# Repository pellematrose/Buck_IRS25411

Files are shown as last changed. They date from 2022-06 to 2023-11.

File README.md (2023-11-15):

# Buck_IRS25411
High Voltage Buck featuring IRS25411 LED driver.
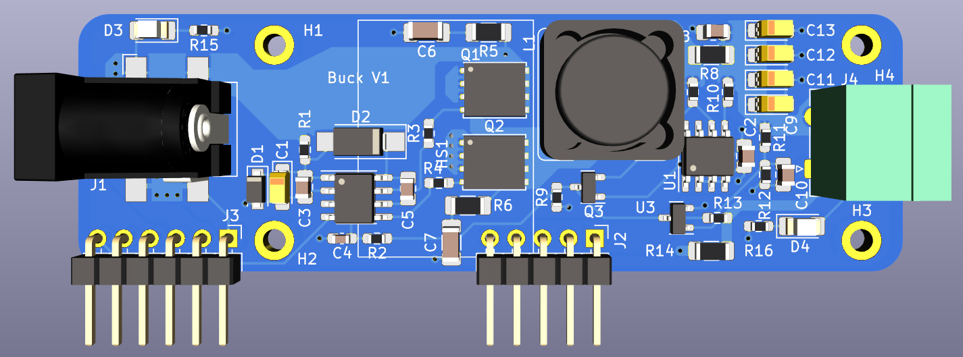
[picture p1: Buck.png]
Buck

The pinheaders offers the opportunity to use it as module on a other PCB.

The IRS25411 is a hysteretic Buck driver for LED applications.
Hysteretic means that there is no fixed frequency but it switches with over and undershooting the threshold level of the feedback pin with the current ripple.
Due to the feedback voltage of 0.5V it is not worth driving more than 1A of current. The needed current sensing resistor results to R = 0.5V / 1A = 0.5Ohms. The power losses are Pls = 0.5V * 1A = 0.5W. This is already to much for a standard 1206 resistor. Using multiple resistors in parallel it might work.

In this design the current sensing resistor moved directly behind the inductor and a op-amp is driving a pnp transistor to provide an appropriate voltage to the feedback pin. Thus, a constant current is maintained.
Additionally, an other part of the circuitry around the TS431 is regulating the voltage.

In parallel operation both CC and CV regulators are active. When the maximum current is flowing the voltage drops and the buck is working in CC mode.
When the maximum current is not flowing the voltage is clipped at the voltage set and the buck is working in CV mode.

The schematic offers the opportunity to assemble the pcb in three ways:
1. Infineon typical application with low side shunt (tested and works)
2. High current CC mode with the op-amp
3. CV mode with TS431 (tested and works)
4. Combined high current CC and CV mode

The design contains a routing mistake:
The connection between VS and Inductor is missing.

Schematics:
1. Infineon typical application with low side shunt
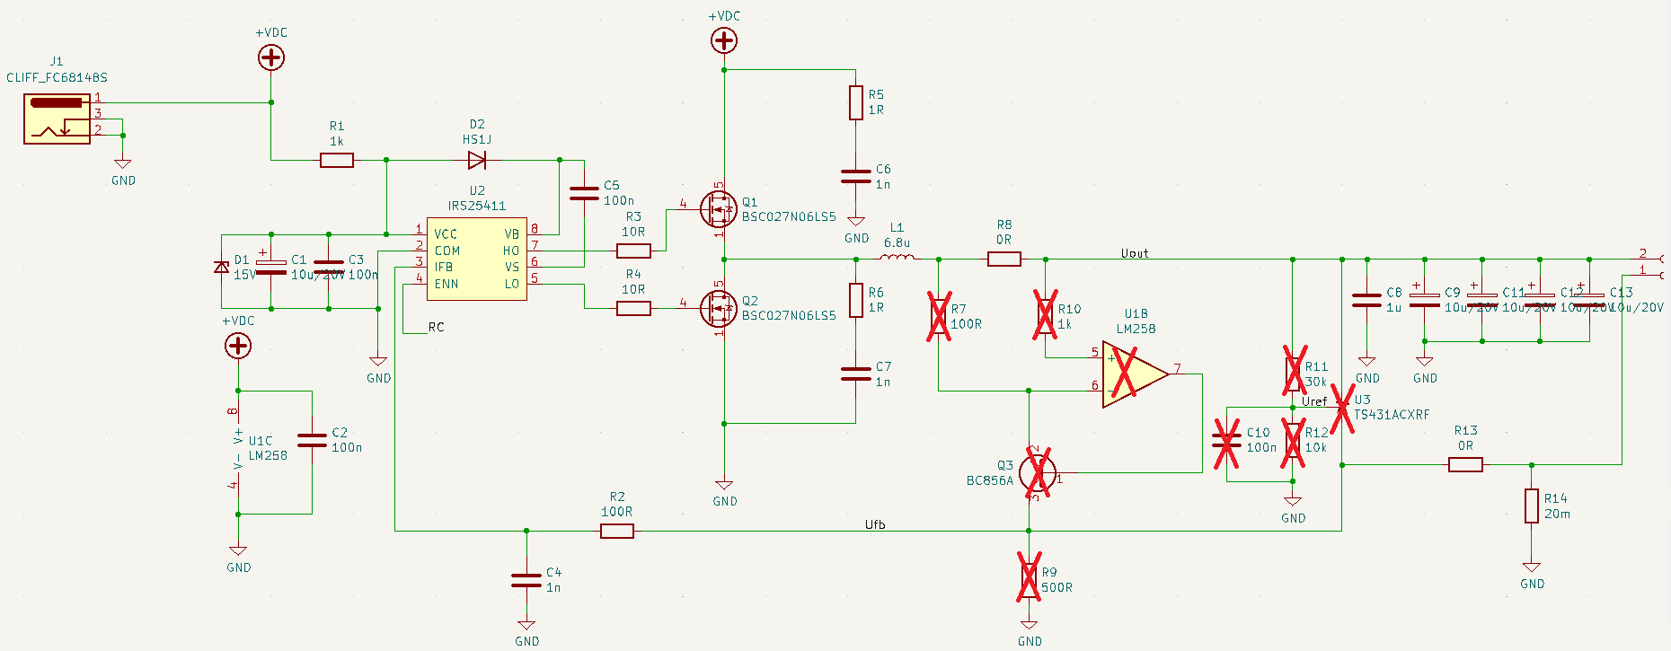
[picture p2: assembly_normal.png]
Buck_Schematic_default


2. High current CC mode with the op-amp
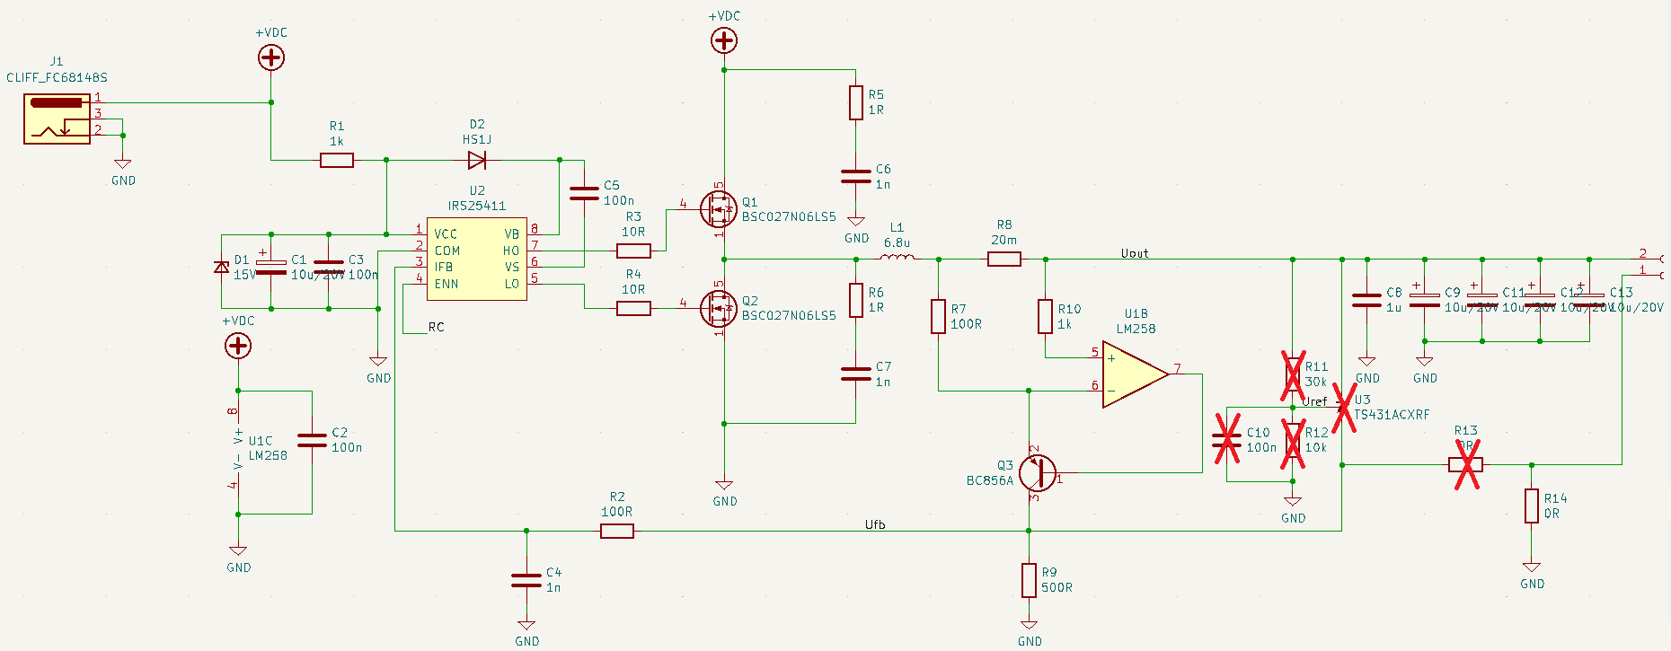
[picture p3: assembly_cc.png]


3. CV mode with TS431
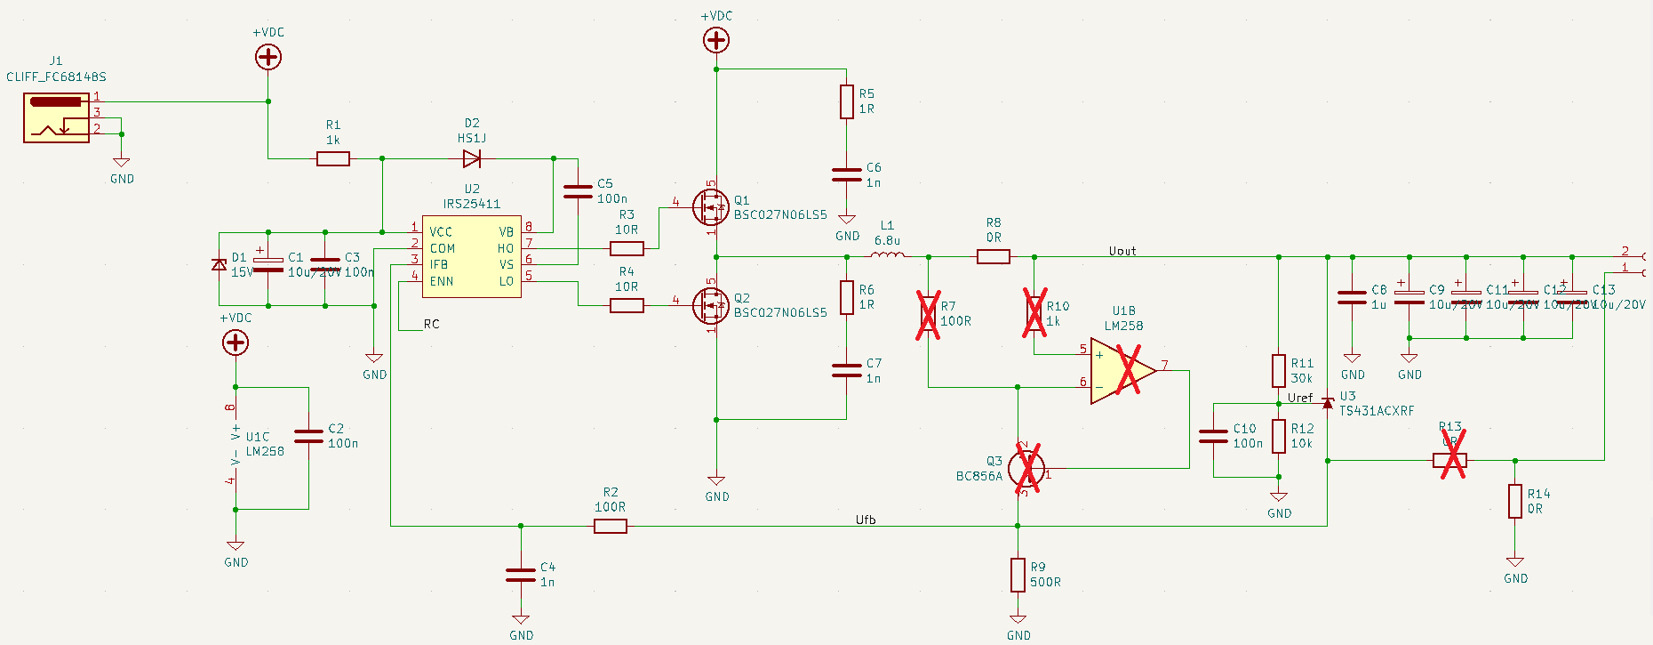
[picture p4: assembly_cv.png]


4. Combined high current CC and CV mode
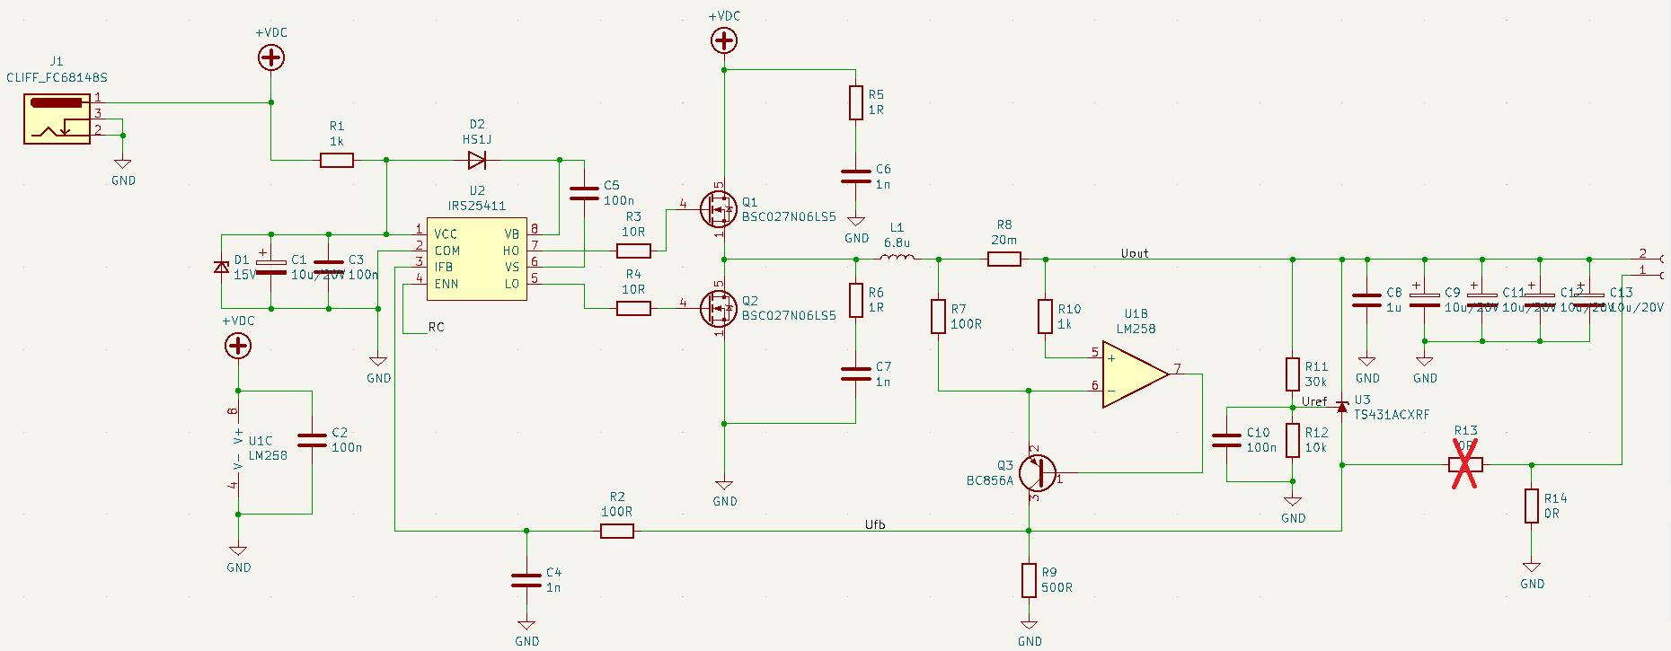
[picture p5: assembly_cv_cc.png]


To make it easy to adjust some component values the excel file may help you understand how the values are calculated.

I got the main inspiration from various application notes about the buck converter.  
[TI CC CV converter](https://www.ti.com/lit/an/snva829/snva829.pdf)  
[Electronics Stackexchange](https://electronics.stackexchange.com/questions/458384/cc-cv-buck-controller)  
[Buck converter design](https://www.mouser.de/pdfdocs/BuckConverterDesignNote.pdf)

Furthermore, here some links to usefull sites about mosfet losses:  
[Infineon MOSFET Losses Appnote](https://community.infineon.com/gfawx74859/attachments/gfawx74859/MOSFET/285/4/MOSFET%20Power%20Losses%20Calculation%20Using%20the%20Data-Sheet%20Parameters.pdf)  
[Youtube with Dr. K](https://www.youtube.com/watch?v=RViwOc4g-gw)</p>

The Buck design is only tested to 30V input voltage.
If you want to make a real high voltage buck you need to recalculate some components:
- R1 to limit the input current to the driver IC
- Q1, Q2 MOSFET Vds rating
- L1 Inductor
- Supply for the OpAmp (only ratet up to 30V)

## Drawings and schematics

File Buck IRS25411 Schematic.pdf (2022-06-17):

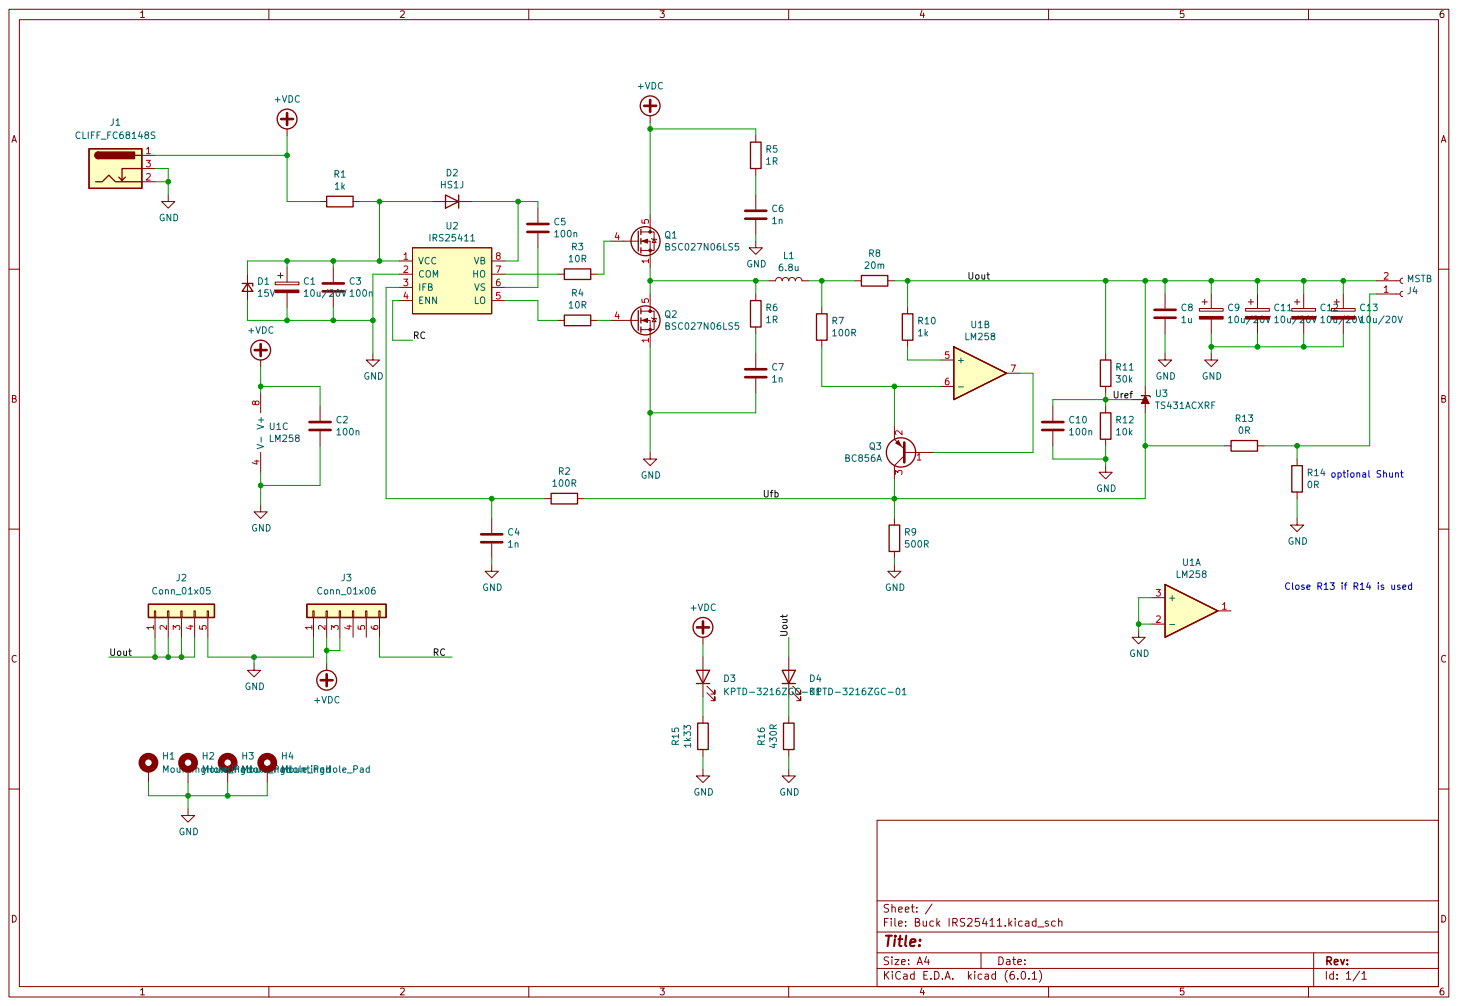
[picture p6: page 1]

VCC 1 COM 2

IFB 3 ENN 4

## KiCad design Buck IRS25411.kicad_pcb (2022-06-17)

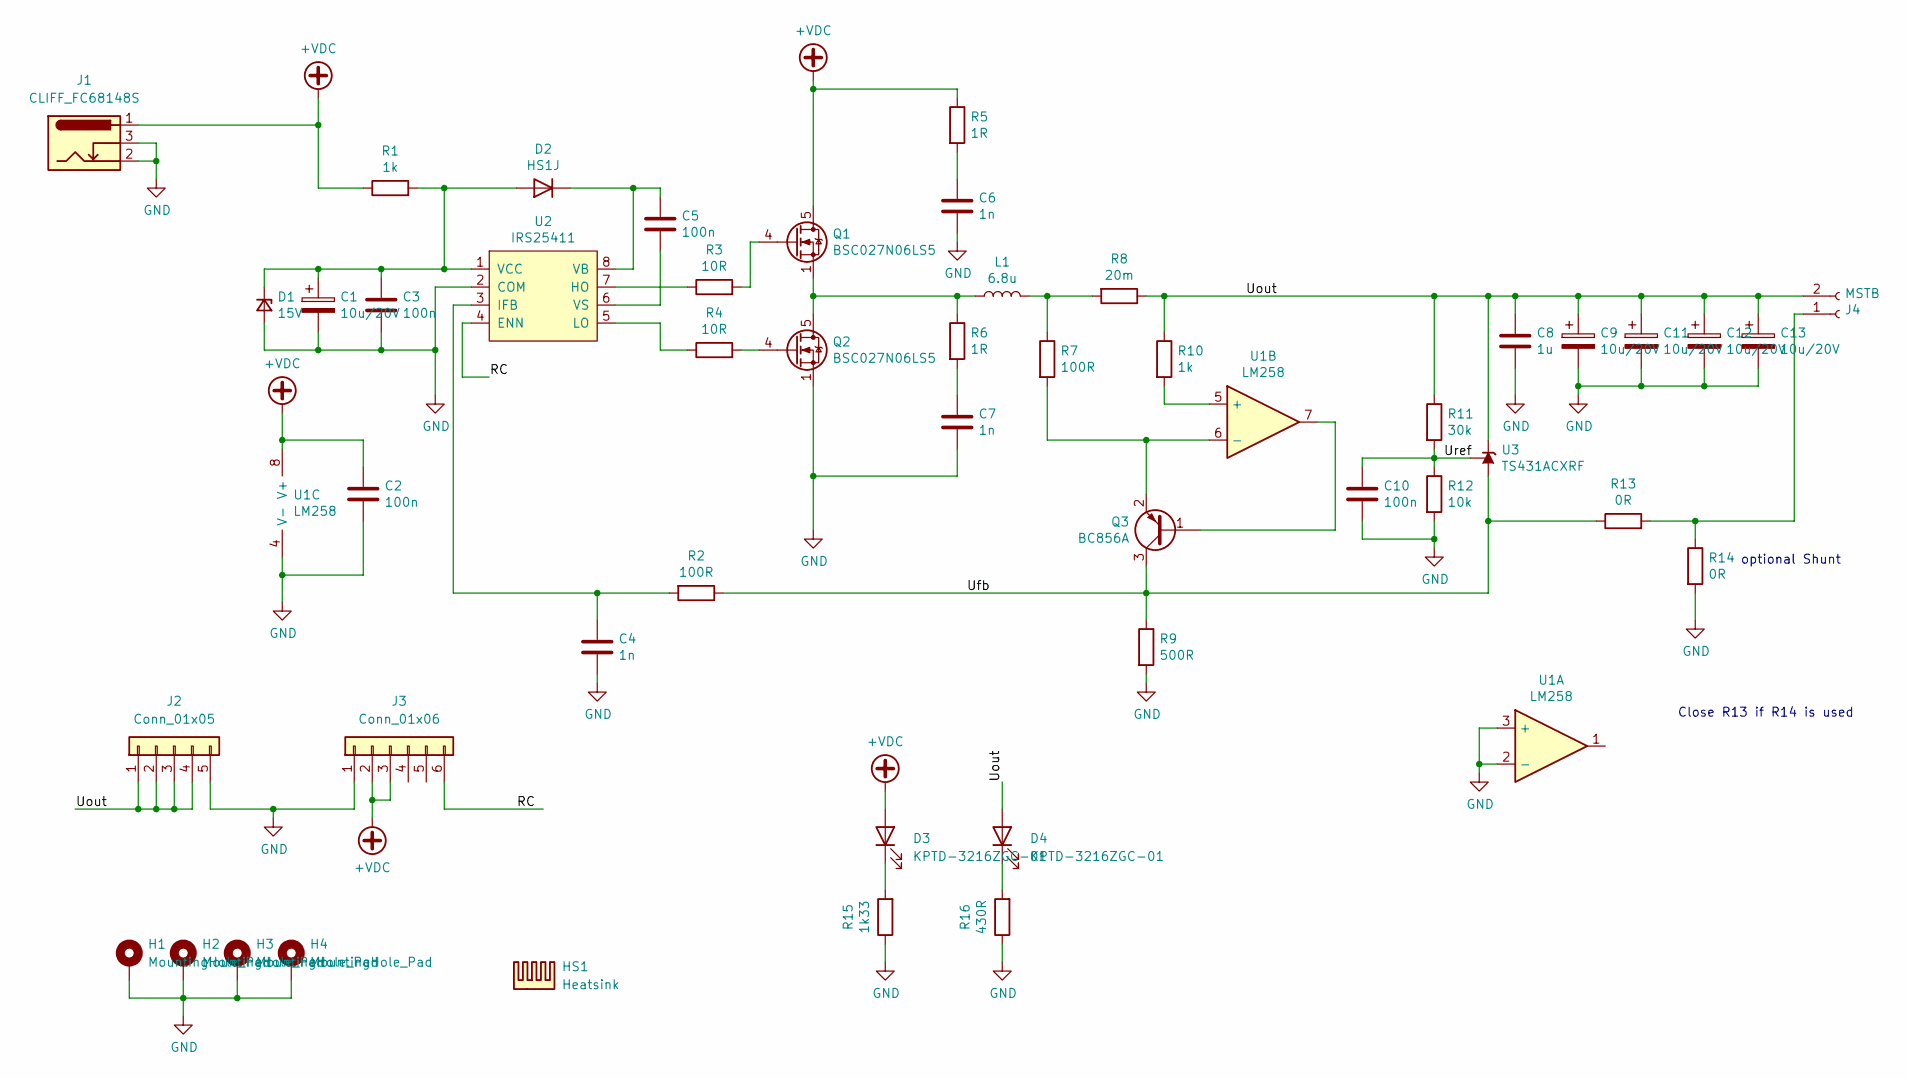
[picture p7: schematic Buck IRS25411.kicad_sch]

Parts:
C1, C9, C11, C12, C13: 10u/20V; CP_EIA-3216-18_Kemet-A_Pad1.58x1.35mm_HandSolder
C2, C3, C5, C10: 100n; C_0805_2012Metric_Pad1.18x1.45mm_HandSolder
C4: 1n; C_0603_1608Metric_Pad1.08x0.95mm_HandSolder
C6, C7: 1n; C_1206_3216Metric_Pad1.33x1.80mm_HandSolder
C8: 1u; C_0805_2012Metric_Pad1.18x1.45mm_HandSolder
D1: 15V; D_SOD-123F
D2: HS1J; D_SMA_Handsoldering
D3, D4: KPTD-3216ZGC-01; LED_1206_3216Metric_Pad1.42x1.75mm_HandSolder
H1, H2, H3, H4: MountingHole_Pad; MountingHole_2.2mm_M2_DIN965_Pad_TopBottom
HS1: Heatsink
J1: CLIFF_FC68148S; BarrelJack_CLIFF_FC681465S_SMT_Horizontal
J2: Conn_01x05; PinHeader_1x05_P2.54mm_Horizontal
J3: Conn_01x06; PinHeader_1x06_P2.54mm_Horizontal
J4: MSTB; PhoenixContact_MC_1,5_2-G-5.08_1x02_P5.08mm_Horizontal
L1: 6.8u; L_Bourns_SRR1260
Q1, Q2: BSC027N06LS5; TDSON-8-1
Q3: BC856A; SOT-23
R1, R10: 1k; R_0603_1608Metric_Pad0.98x0.95mm_HandSolder
R2, R7: 100R; R_0603_1608Metric_Pad0.98x0.95mm_HandSolder
R3, R4: 10R; R_0603_1608Metric_Pad0.98x0.95mm_HandSolder
R5, R6: 1R; R_1206_3216Metric_Pad1.30x1.75mm_HandSolder
R8: 20m; R_1206_3216Metric_Pad1.30x1.75mm_HandSolder
R9: 500R; R_0603_1608Metric_Pad0.98x0.95mm_HandSolder
R11: 30k; R_0603_1608Metric_Pad0.98x0.95mm_HandSolder
R12: 10k; R_0603_1608Metric_Pad0.98x0.95mm_HandSolder
R13: 0R; R_0603_1608Metric_Pad0.98x0.95mm_HandSolder
R14: 0R; R_1206_3216Metric_Pad1.30x1.75mm_HandSolder
R15: 1k33; R_0603_1608Metric_Pad0.98x0.95mm_HandSolder
R16: 430R; R_0603_1608Metric_Pad0.98x0.95mm_HandSolder
U1: LM258; SOIC-8_3.9x4.9mm_P1.27mm
U2: IRS25411; SOIC-8_3.9x4.9mm_P1.27mm
U3: TS431ACXRF; SOT-23

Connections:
+VDC: C2.1, D3.2 (A), J1.1, J3.2, J3.3, Q1.5 (D), R1.1, R5.1, U1.8 (V+)
/RC: J3.6, U2.4 (ENN)
/Ufb: Q3.3 (C), R2.1, R9.1, R13.1, U3.3 (A)
/Uout: C8.1, C9.1, C11.1, C12.1, C13.1, D4.2 (A), J2.1, J2.2, J2.3, J2.4, J4.2, R8.1, R10.1, R11.1, U3.2 (K)
/Uref: C10.1, R11.2, R12.1, U3.1 (REF)
GND: C1.2, C2.2, C3.2, C4.2, C6.2, C7.2, C8.2, C9.2, C10.2, C11.2, C12.2, C13.2, D1.2 (A), H1.1, H2.1, H3.1, H4.1, J1.2, J1.3, J2.5, J3.1, Q2.1 (S), Q2.2 (S), Q2.3 (S), R9.2, R12.2, R14.2, R15.1, R16.1, U1.2 (-), U1.3 (+), U1.4 (V-), U2.2 (COM)
unnamed: C1.1, C3.1, D1.1 (K), D2.2 (A), R1.2, U2.1 (VCC)
unnamed: C4.1, R2.2, U2.3 (IFB)
unnamed: C5.1, D2.1 (K), U2.8 (VB)
unnamed: C5.2, U2.6 (VS)
unnamed: C6.1, R5.2
unnamed: C7.1, R6.2
unnamed: D3.1 (K), R15.2
unnamed: D4.1 (K), R16.2
unnamed: J4.1, R13.2, R14.1
unnamed: L1.1, Q1.1 (S), Q1.2 (S), Q1.3 (S), Q2.5 (D), R6.1
unnamed: L1.2, R7.1, R8.2
unnamed: Q1.4 (G), R3.2
unnamed: Q3.1 (B), U1.7
unnamed: Q3.2 (E), R7.2, U1.6 (-)
unnamed: R3.1, U2.7 (HO)
unnamed: R4.1, U2.5 (LO)
unnamed: Q2.4 (G), R4.2
unnamed: R10.2, U1.5 (+)

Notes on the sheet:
Close R13 if R14 is used
optional Shunt

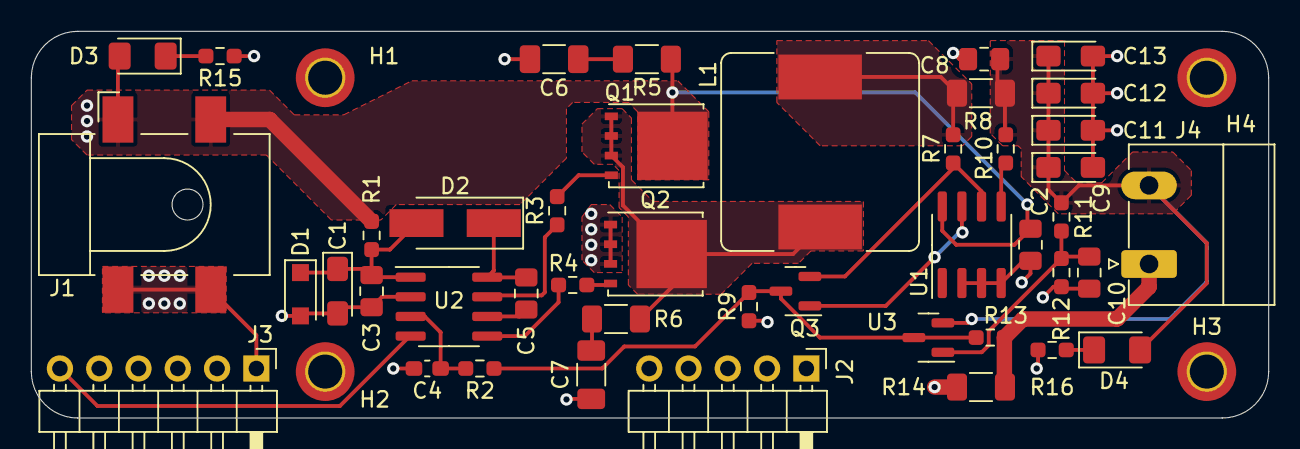
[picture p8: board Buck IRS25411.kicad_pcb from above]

Board: 2 copper layers, 80.0 x 25.0 mm, 48 parts (0 on the bottom side), 24 nets.

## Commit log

2022-06-17 Add files via upload
    added gerber files
    [Buck IRS25411-B_Cu.gbr, Buck IRS25411-B_Mask.gbr, Buck IRS25411-B_Paste.gbr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]
2022-06-17 Add files via upload
    Added KiCad files
    [Buck IRS25411.kicad_pcb, Buck IRS25411.kicad_sch]
2022-06-17 Add files via upload
    added schematic pdf
2022-06-17 Add files via upload
    added excel file for calculations
    [Synchronbuck IRS25411.ods]
2022-06-17 Add files via upload
    added a picture of the buck
